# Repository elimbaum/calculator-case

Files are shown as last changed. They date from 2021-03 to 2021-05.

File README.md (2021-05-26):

# calculator-case
openscad design of case for sinclair scientific emulator ([tindie][1], [hackaday][2], [github][3])

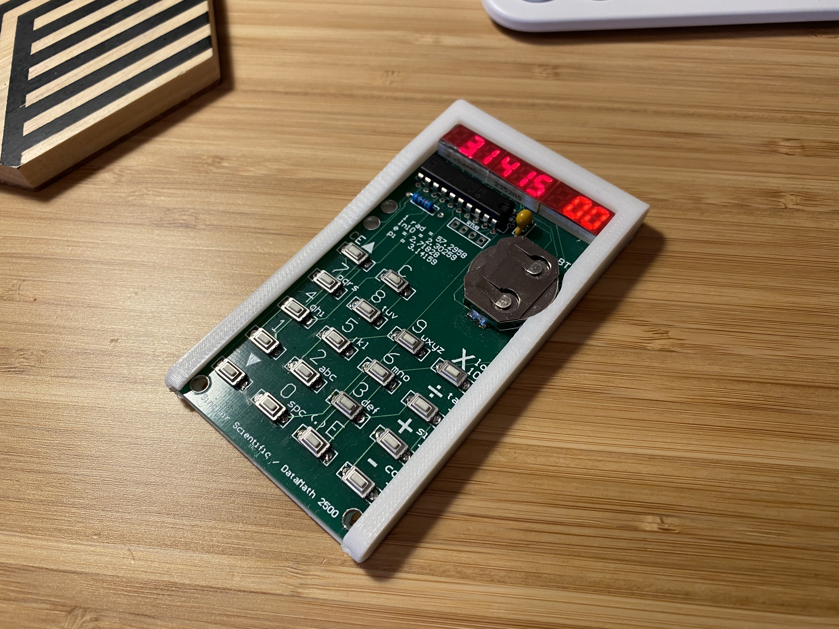
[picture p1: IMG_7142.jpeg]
version 3 image


[1]: https://www.tindie.com/products/simpleavr/ti-msp430-emulating-calculator-kit/#product-description
[2]: https://hackaday.io/project/167780-ti-msp430-emulating-calculator
[3]: https://github.com/simpleavr/tms0800

## Files
- **case.scad** the main design
- **definitons.scad** all measurements
- **plugs.scad** simple plugs to hold the PCB in place (through mounting holes)
- stl:
  - v1: original, native inches
  - v2: scaled up to use native mm
  - v3: adjustments after first print

## Notes

### Special keycodes
I always forget these and get stuck. Copying them here to prevent that.

- C+5 = button test ('C'+'C' to end test)
- C+6 = secret message edit (+ key to advance) *(eli note: to cancel, press + key a bunch)*
- C+7 = toggle datamath / sinclair roms
- C+8 = toggle slow / fast cpu
- C+9 = show secret message
- C+C = turn off (put to sleep)

### Initial prototype (v1/2)

Couple of issues.

- Slot for PCB isn't quite tall enough to fit the soldered leads. The PCB itself fits nicely. I think I should have a two-layer design: keep the slot as is, but then depress the back a bit so the leads have room.
- Battery is just entirely in the wrong place. I don't think I actually ever measured it.
- Plugs are way too small. I think I should try squares or ovals so that there's some room for form-fitting.

I'm thinking of writing a function that takes care of adjustments for me:

```scad
LENGTH = 5;
// becomes
LENGTH = adj(orig=5, meas=5.1);
```

Nah, maybe not worth it.

Plugs were supposed to be diameter 0.125, and are more like 0.115. Holes came out right, however (0.135). I want to make the plugs ellipses, so the major axis should be a bit too big and the minor a bit small. This may need further adjustment, but I can always hack this together, or just print new ones.

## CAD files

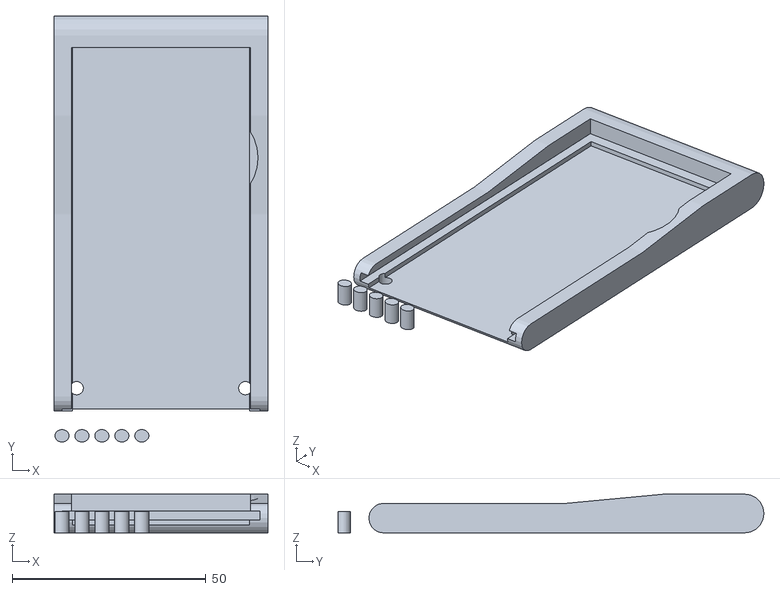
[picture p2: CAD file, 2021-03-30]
case_v3.stl
55.1 x 109.8 x 10.0

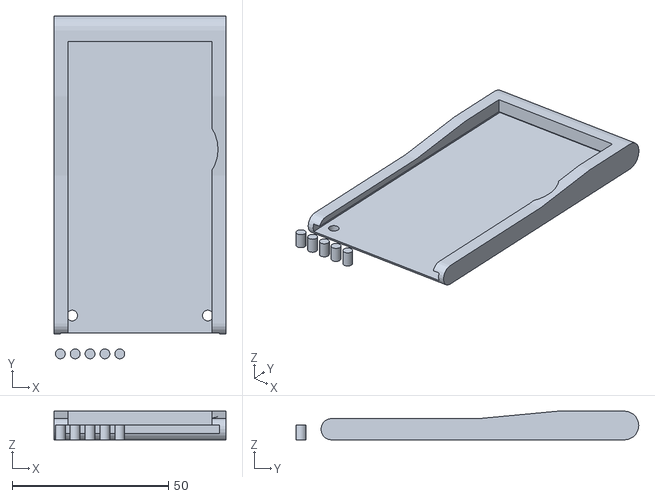
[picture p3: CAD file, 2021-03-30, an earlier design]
case_v2.stl
55.1 x 109.8 x 9.25

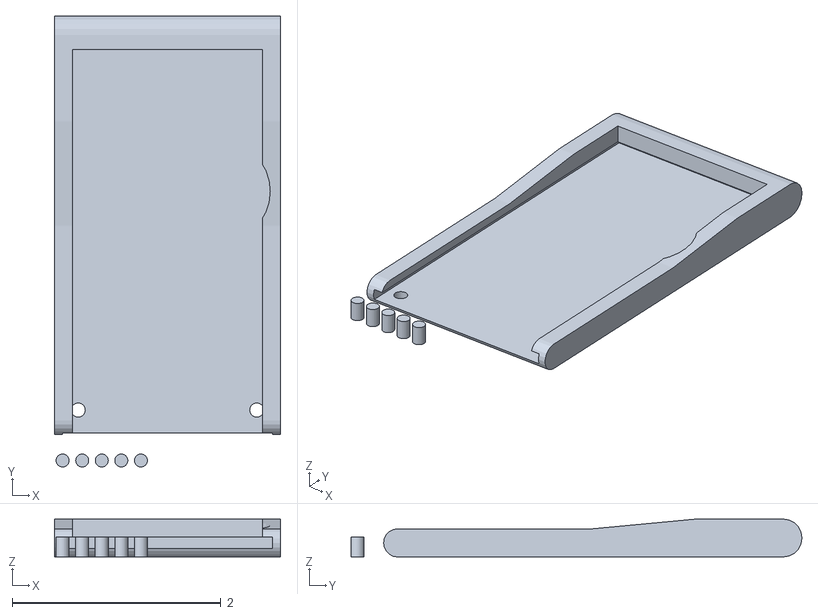
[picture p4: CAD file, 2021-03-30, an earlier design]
case_v1.stl
2.17 x 4.32 x 0.364

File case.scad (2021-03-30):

// units: inch
include <Round-Anything/polyround.scad>;
include <definitions.scad>;

// TODO:
// snaps
// battery molding


module mounting_holes() {
    // two mounting holes @ bottom
    translate([0, HOLE_POS.y + HOLE_RAD, -CASE_THICKNESS-TOL]) {
        hole_x_offset = HOLE_POS.x + HOLE_RAD;
        hole_height = 2*TOL + PCB_DIM.z + CASE_THICKNESS + SOLDER_LEAD_DIM.z;
        translate([hole_x_offset, 0, -SOLDER_LEAD_DIM.z]) {
            cylinder(r=HOLE_RAD, h=hole_height);
        }
        
        translate([PCB_DIM.x - hole_x_offset, 0, -SOLDER_LEAD_DIM.z]) {
            cylinder(r=HOLE_RAD, h=hole_height);
        }
    }  
}

module calculator() {
    // circuit board
    color("green")
    difference() {
        cube(PCB_DIM);
        
        mounting_holes();
        
    }
    
    // display
    color("red")
    translate(
        [(PCB_DIM.x - SCREEN_DIM.x) / 2,
         PCB_DIM.y - SCREEN_DIM.y - SCREEN_OFFSET,
         PCB_DIM.z - TOL])
    {
        cube([0, 0, TOL] + SCREEN_DIM);
    }
    
    // battery
    color("gray")
    translate(
        [PCB_DIM.x - BATT_POS.x - BATT_RAD,
         PCB_DIM.y - BATT_POS.y - BATT_RAD,
         PCB_DIM.z - TOL])
    {
        cylinder(r=BATT_RAD, h=BATT_HEIGHT);
    }
    
    // solder leads
    color("gray")
    translate([
                (PCB_DIM.x - SOLDER_LEAD_DIM.x)/2,
                PCB_DIM.y - SOLDER_LEAD_DIM.y - SCREEN_OFFSET,
                -SOLDER_LEAD_DIM.z]) {
        cube(SOLDER_LEAD_DIM);
    }
    
}

module case() {
    color("yellow", 0.3) {
//        cube([CASE_WIDTH, CASE_BASE_LENGTH, CASE_BASE_HEIGHT]);
//        translate([0, CASE_BASE_LENGTH, 0])
//            cube([CASE_WIDTH, CASE_TOP_LENGTH, CASE_TOP_HEIGHT]);
        
        // case profile
        rotate([90, 0, 90])
            linear_extrude(CASE_WIDTH)
            polygon(polyRound([
                     [0, 0, CASE_ROUND],
                     [FULL_CASE_LENGTH, 0, CASE_ROUND],
                     [FULL_CASE_LENGTH, CASE_TOP_HEIGHT, CASE_ROUND],
                     [FULL_CASE_LENGTH - CASE_TOP_LENGTH,
                        CASE_TOP_HEIGHT, CASE_ROUND],
                     [CASE_BASE_LENGTH, CASE_BASE_HEIGHT, CASE_ROUND],
                     [0, CASE_BASE_HEIGHT, CASE_ROUND]]));
    }
}

module screen_profile(extrude_amt) {
    rotate([90, -90, 180])
    linear_extrude(extrude_amt)
    projection(cut = true)
    rotate([90, 0, 90])
    translate([0, - (PCB_DIM.y - SCREEN_OFFSET - SCREEN_DIM.y/2), 0])
    calculator();
}

module battery_profile(extrude_amt) {
    rotate([90, -90, 180])
    linear_extrude(extrude_amt)
    projection(cut = true)
    rotate([90, 0, 90])
    translate([0, - (PCB_DIM.y - BATT_POS.y - BATT_RAD), 0])
    calculator();
}

module cutout() {
    union() {
        translate([0, -(CASE_THICKNESS+TOL), 0]) {
            screen_profile(PCB_DIM.y - SCREEN_OFFSET);
            battery_profile(PCB_DIM.y - BATT_POS.y + CASE_THICKNESS);
        }
        mounting_holes();
        
        // battery cutout
        translate(
            [PCB_DIM.x - BATT_POS.x - BATT_RAD,
             PCB_DIM.y - BATT_POS.y - BATT_RAD,
             PCB_DIM.z - TOL])
        {
            cylinder(r=BATT_RAD + BATT_CUTOUT_ADJ, h=BATT_HEIGHT);
        }
        
        // full calculator, just to make sure
        calculator();
    }    
}

scale(25.4) {

translate([0, CASE_THICKNESS, CASE_THICKNESS + SOLDER_LEAD_DIM.z]) {
    if ($preview) calculator();

    difference() {
        translate([-CASE_THICKNESS,
                   -CASE_THICKNESS,
                   -CASE_THICKNESS - SOLDER_LEAD_DIM.z])
            case();
           
        cutout();
    }
}

translate([0, -0.25, 0]) {
    include <plugs.scad>;
}
}
//cutout();

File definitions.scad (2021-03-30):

TOL = 0.001;

//$fa = 1;
$fs = 0.01;

PCB_WIDTH_ADJ = 0.01;
PCB_HEIGHT_ADJ = 0.03;

SCREEN_WIDTH_ADJ = 0.01;

// CALCULATOR DEFINITIONS
PCB_DIM = [2 + PCB_WIDTH_ADJ, 3.75, 0.06 + PCB_HEIGHT_ADJ];
SCREEN_DIM = [1.81 + SCREEN_WIDTH_ADJ, 0.325, 0.175];

SCREEN_OFFSET = 0.14; // from top

SOLDER_LEAD_DIM = [1.8, 1, 0.05]; // y dim approx

HOLE_DIAM = 0.135;
HOLE_POS = [0.082, 0.086];
HOLE_RAD = HOLE_DIAM / 2;

BATT_DIAM = 0.787;
BATT_HEIGHT = 0.2;
BATT_POS = [0.12, 0.865];
BATT_RAD = BATT_DIAM / 2;

BATT_CUTOUT_ADJ = 0.1;

// CASE DEFINITIONS
CASE_THICKNESS = 0.08;
CASE_WIDTH = PCB_DIM.x + 2 * CASE_THICKNESS;

CASE_BASE_HEIGHT = PCB_DIM.z + 2 * CASE_THICKNESS + SOLDER_LEAD_DIM.z;
CASE_BASE_LENGTH = 2;

CASE_MID_LENGTH = 1;

CASE_EXTRA = 0.1;
FULL_CASE_LENGTH = PCB_DIM.y + 2 * CASE_THICKNESS + CASE_EXTRA;

//echo(FULL_CASE_LENGTH, CASE_WIDTH);

CASE_TOP_HEIGHT = SOLDER_LEAD_DIM.z + CASE_THICKNESS + PCB_DIM.z + SCREEN_DIM.z - TOL;
CASE_TOP_LENGTH = FULL_CASE_LENGTH - CASE_BASE_LENGTH - CASE_MID_LENGTH;

CASE_ROUND = 0.25;

PLUG_ADJ = 0.009;
PLUG_DIAM = HOLE_DIAM;

NUM_PLUGS = 5;

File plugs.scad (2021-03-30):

include <definitions.scad>;

for (p = [0:NUM_PLUGS-1]) {
    translate([(1.5 * p) * PLUG_DIAM, 0, 0])
    resize([PLUG_DIAM + PLUG_ADJ, PLUG_DIAM - PLUG_ADJ, 0])
    cylinder(r=1, h=PCB_DIM.z + CASE_THICKNESS + SOLDER_LEAD_DIM.z - TOL);
}

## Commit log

2021-03-30 first version stl
    [case.scad, case_v1.stl, case_v2.stl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]
2021-03-30 Notes on prototype
2021-03-30 adjustments to first prototype
    [case.scad, case_v3.stl, definitions.scad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]
